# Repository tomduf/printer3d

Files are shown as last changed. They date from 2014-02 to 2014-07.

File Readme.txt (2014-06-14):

Imprimante 3D
Lycée Condorcet - Montreuil

1. Origine du projet
Suite à la découverte de l'expérience "manuelle" d'imprimante 3D proposée par l'université de l'Illinois,
l'idée est venue de proposer la réalisation d'un imprimante 3D dans le cadre des projets pluridisciplinaires de
Terminale SI (Sciences de l'Ingénieur).
Une équipe de quatre élèves a choisi ce projet en septembre 2012 :
- Ludovic Araujo
- Thomas Bande
- Max Dumesny
- Clément Soriot

2. Première version
À l'issue du projet  (juin 2013), un prototype fonctionnel mais non finalisé a permis l'impression d'une petite pièce
très détaillée.
La résine a été synthétisée par un professeur du laboratoire de physique-chimie (Nicolas Dubuisson) selon les
recommandations du site de l'Université de l'Illinois.
L'affichage s'effectuait par vidéoprojecteur DPL et un PC via un programme Processing.
La commande du moteur était réalisée par une carte contrôleur Arduino Uno.
Le PC et l'Arduino Uno communiquaient par port série.

3. Version acutelle en cours de développement (2014)
Le projet a été repris avec un objectif de portabilité totale :
- plus de PC externe
- une alimentation unique
- un accès wifi / Ethernet
- un clavier / souris intégré
- transportabilité manuelle

4. La solution retenue est la suivante :
- Raspberry Pi pour le logiciel d'affichage DLP et gestion du serveur d'images
- Serveur node.js
- Affichage par navigateur web (chromium ou autre) avec jquery
- Arduino Uno pour la commande moteur et l'affichage sur petit écran Oled
- Miroir basculant permettant d'afficher les instructions au mur via le vidéoprojecteur
- Clavier / Souris articulé
- Poignée de transport

5. Exécution logiciel
- Ouvrir un terminal
- Lancer l'application sur le Raspberry avec la commande node app.js
- Observer le déroulement du programme dans la console
- Lancer sur le navigateur web http://localhost:3000
- Suivre les instructions

Thomas DUFOUR
Professeur de Sciences de l'Ingénieur
Lycée Condorcet
31 rue Désiré Chevalier
93100 MONTREUIL

thomas.dufour@condorcet93.fr

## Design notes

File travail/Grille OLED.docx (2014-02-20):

Mode drawFastVLine(48, 0, 48, WHITE); | Cycle drawFastHLine(0, 48, 96, WHITE); drawFastHLine(0, 32, 96, WHITE); drawFastHLine(0, 16, 96, WHITE);
Couche | 43 / 57
Hauteur | -0.32 mm
État | > Up ...

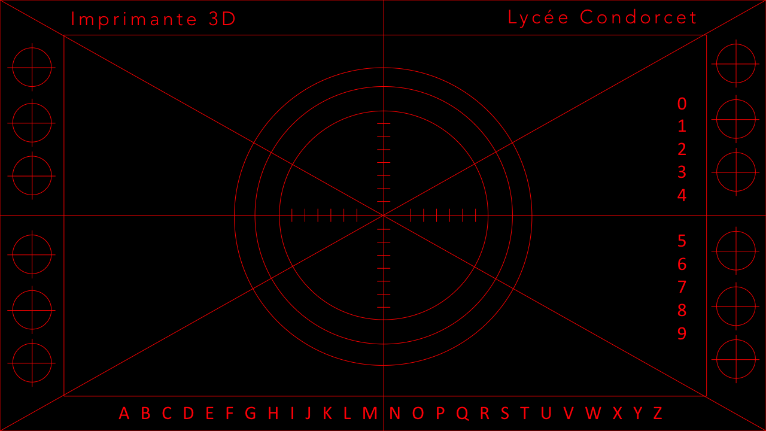
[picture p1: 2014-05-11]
public/images/mire_mise_au_point.png

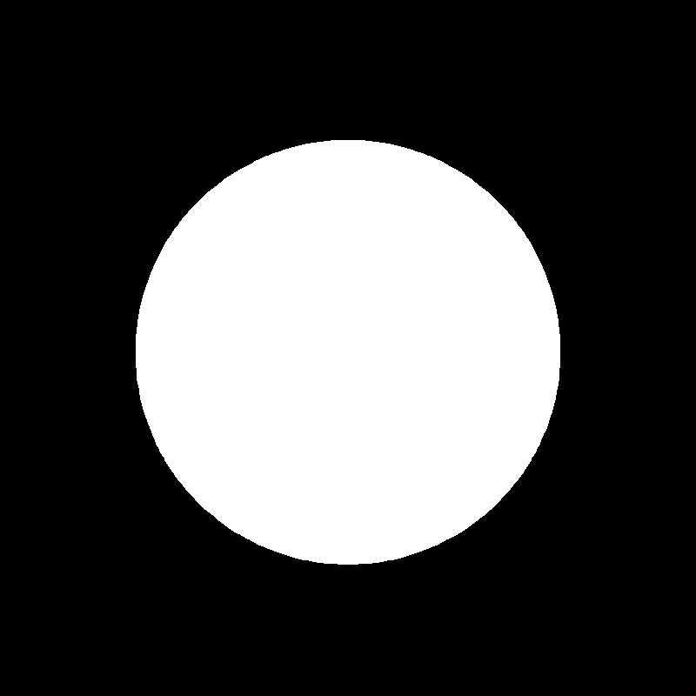
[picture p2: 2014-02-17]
travail/slices-octo-57/layer_0040(z=40.001).png

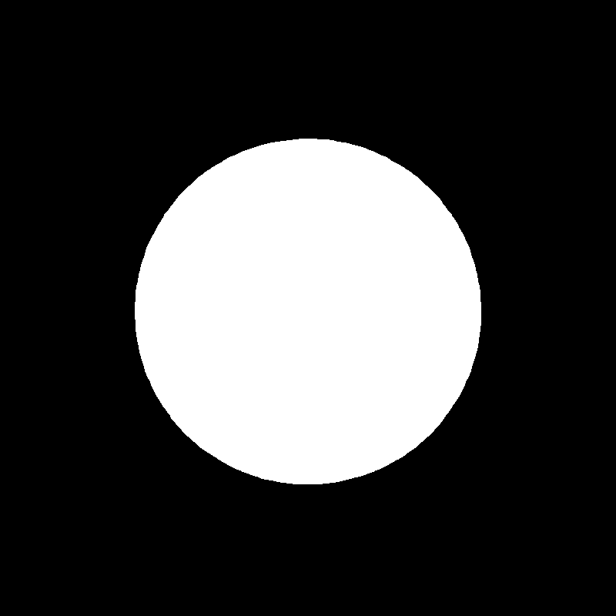
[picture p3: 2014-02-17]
travail/slices-octo-57/layer_0045(z=45.001).png

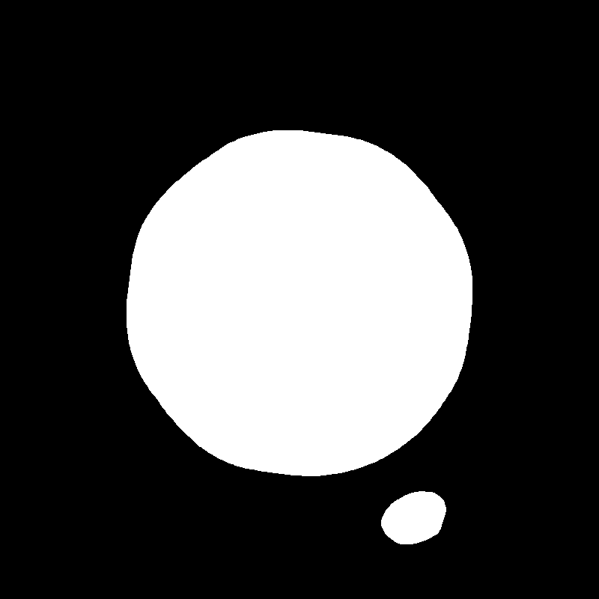
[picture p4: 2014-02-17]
travail/slices-octo-57/layer_0017(z=17.000).png

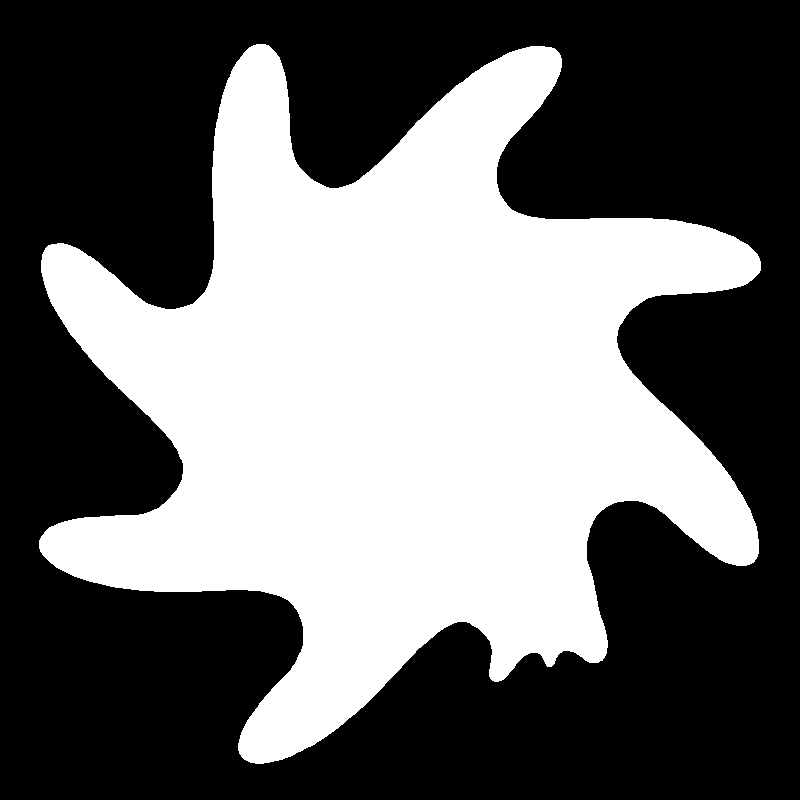
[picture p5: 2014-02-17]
travail/slices-ocot-10/layer_0003(z=3.001).png

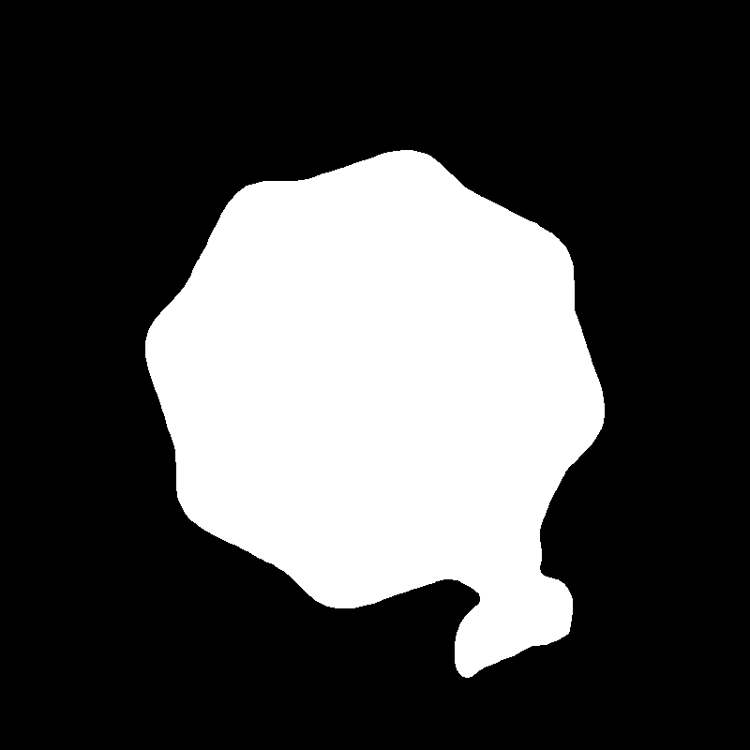
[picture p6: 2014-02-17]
travail/slices-ocot-10/layer_0008(z=8.000).png

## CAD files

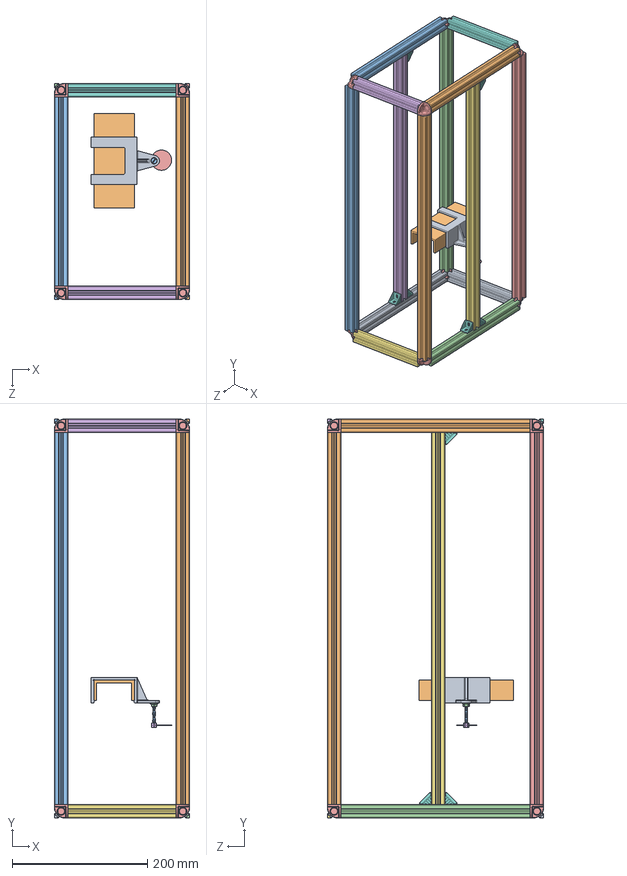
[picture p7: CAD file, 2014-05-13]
travail/solidworks/printer3d.SLDASM
200.0 x 590.0 x 320.0 mm
Profilé - 20x20x280mm - 2
Profilé - 20x20x280mm - 1
Profilé - 20x20x280mm - 3
Profilé - 20x20x280mm - 4
Cornière d'angle - rainure 6mm x 8
Profilé - 20x20x160mm - 1
Profilé - 20x20x160mm - 2
Profilé - 20x20x160mm - 3
Profilé - 20x20x160mm - 4
Profilé - 20x20x550mm - 1
Profilé - 20x20x550mm - 2
Profilé - 20x20x550mm - 3
Profilé - 20x20x550mm - 4
Profilé - 20x20x550mm - 5
Profilé - 20x20x550mm - 6
Equerre x 6
Support clipsable
Copie de Cornière alu^Coulisseau - Plongeur_printer3d
slotted countersunk flat head screw_iso
hex flange nut gradea_iso
Copie de Disque^Coulisseau - Plongeur_printer3d
hex nut style 1 gradeab_iso x 2

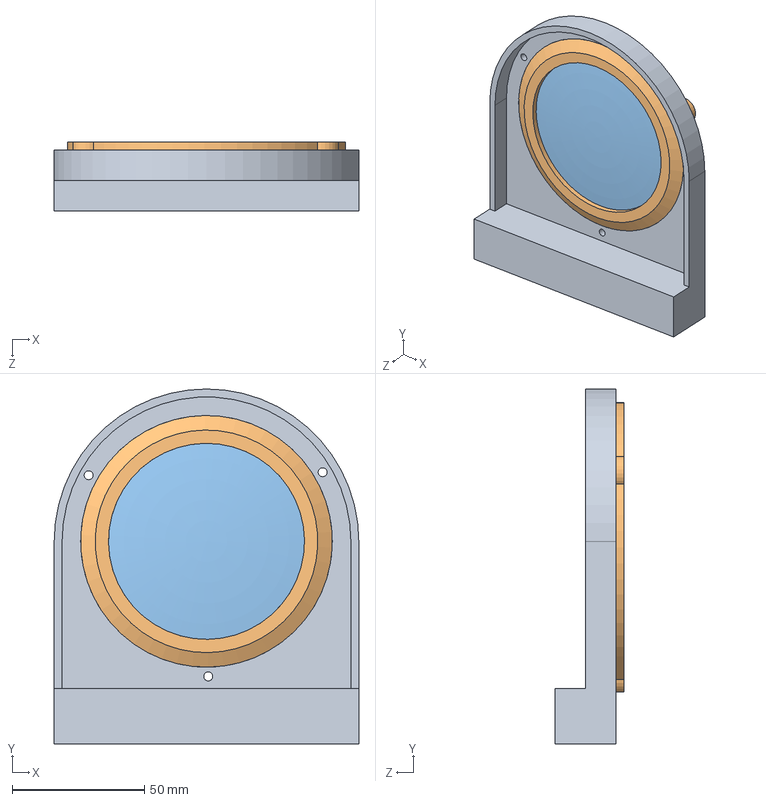
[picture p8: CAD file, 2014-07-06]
travail/Support lentille articulé.SLDASM
115.0 x 134.0 x 26.0 mm
Support lentille
Pièce adaptatrice lentille
Lentille

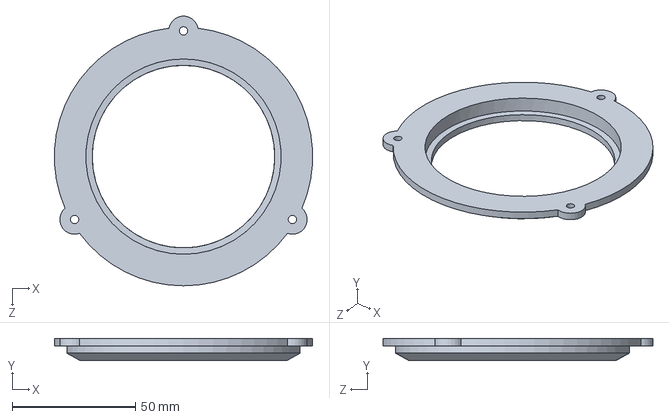
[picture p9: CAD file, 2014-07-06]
travail/Pièce adaptatrice lentille.SLDPRT
104.6 x 9.00 x 109.4 mm

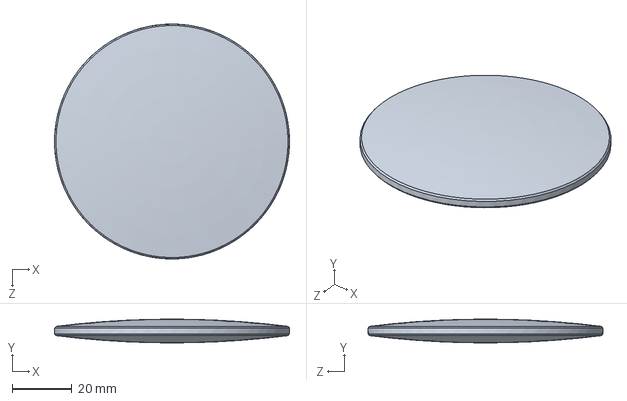
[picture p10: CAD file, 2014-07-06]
travail/Lentille.SLDPRT
79.0 x 8.00 x 79.0 mm

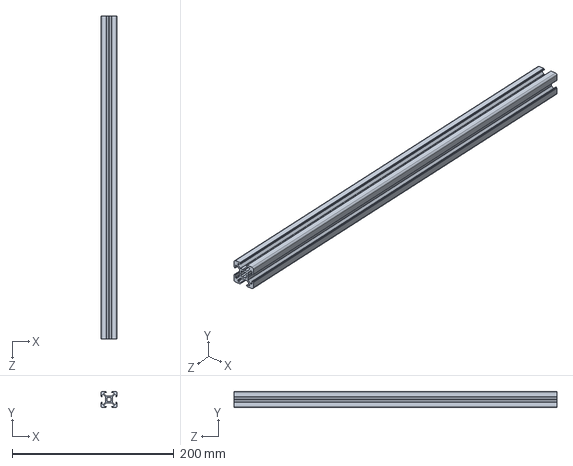
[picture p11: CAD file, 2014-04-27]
travail/solidworks/Profilé - 20x20x550mm - 5.SLDPRT
20.0 x 20.0 x 400.0 mm

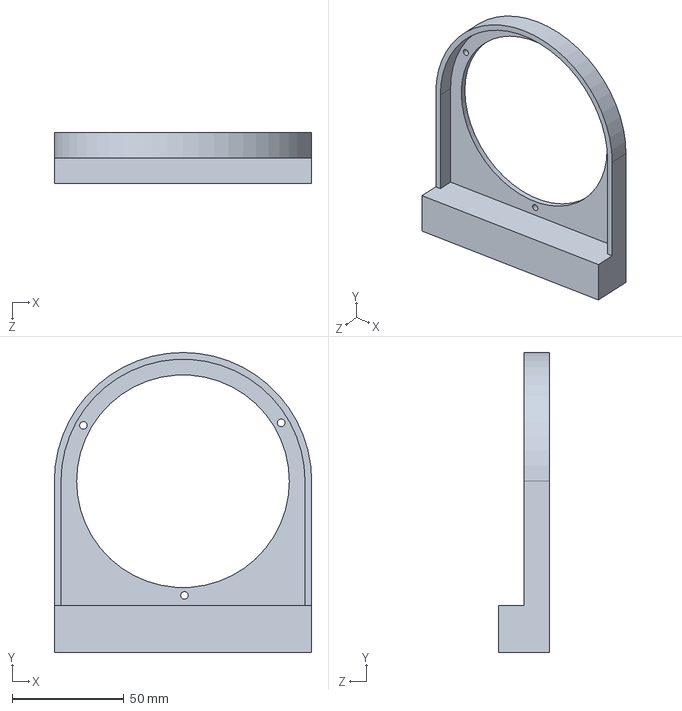
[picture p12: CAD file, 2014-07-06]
travail/Support lentille.SLDPRT
115.0 x 134.0 x 23.0 mm

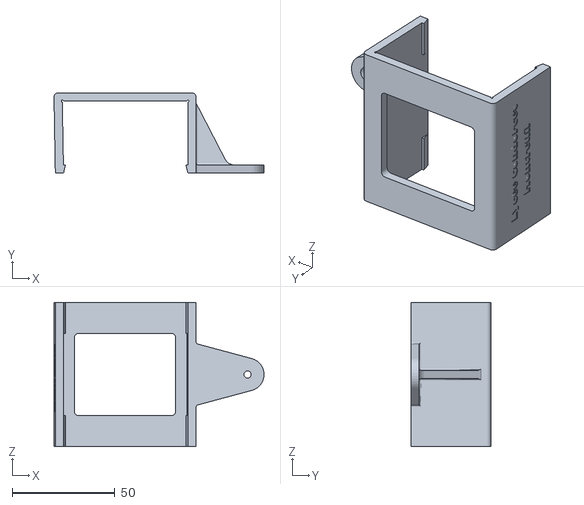
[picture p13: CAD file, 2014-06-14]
travail/Support clipsable.STL
102.0 x 39.0 x 70.0

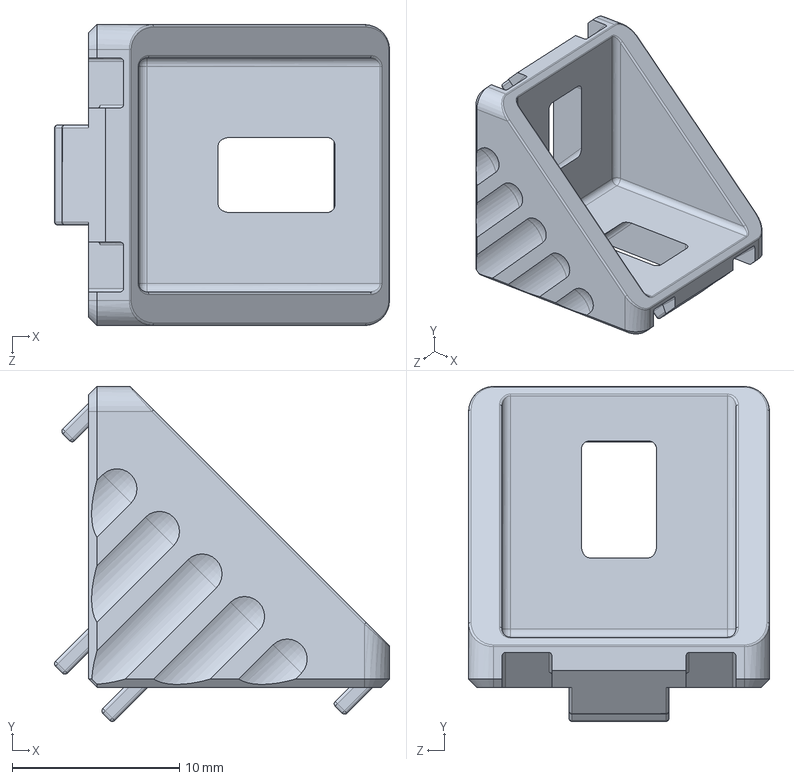
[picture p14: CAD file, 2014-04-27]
travail/solidworks/Equerre.SLDPRT
20.0 x 20.0 x 18.0 mm

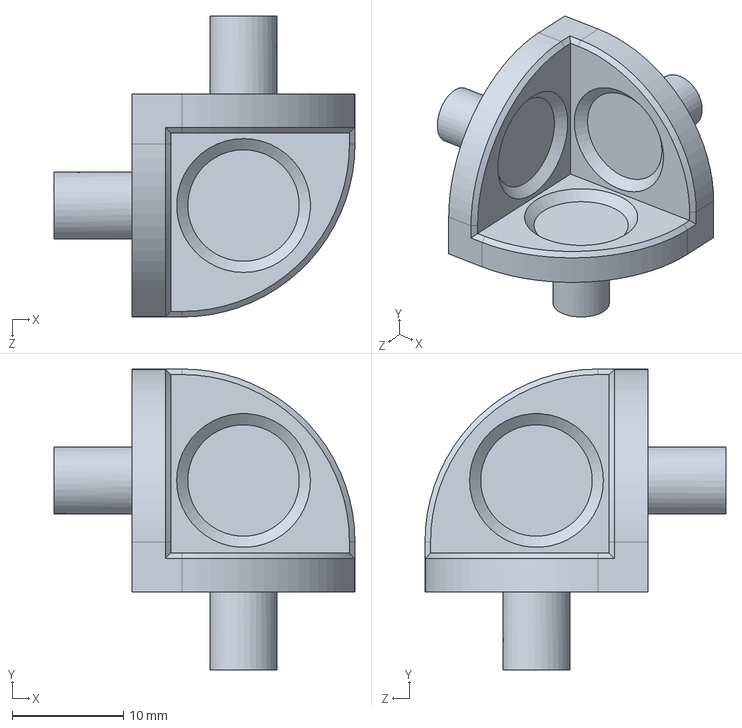
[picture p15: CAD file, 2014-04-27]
travail/solidworks/Cornière d'angle - rainure 6mm.SLDPRT
27.0 x 27.0 x 27.0 mm

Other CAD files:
travail/solidworks/Profilé - 20x20x160mm - 4.SLDPRT
travail/solidworks/Profilé - 20x20x160mm - 1.SLDPRT
travail/solidworks/Profilé - 20x20x280mm - 1.SLDPRT
travail/solidworks/Profilé - 20x20x280mm - 4.SLDPRT
travail/solidworks/Profilé - 20x20x280mm - 2.SLDPRT
travail/Pièce adaptatrice lentille.STL
travail/Support lentille articulé.SLDDRW
travail/solidworks/Profilé - 20x20x160mm - 2.SLDPRT
travail/solidworks/Profilé - 20x20x160mm - 3.SLDPRT
travail/solidworks/Profilé - 20x20x280mm - 3.SLDPRT
travail/solidworks/Rexroth-3 842 992 888_400MM.SLDPRT
travail/solidworks/Rexroth-ecrou M4.SLDPRT

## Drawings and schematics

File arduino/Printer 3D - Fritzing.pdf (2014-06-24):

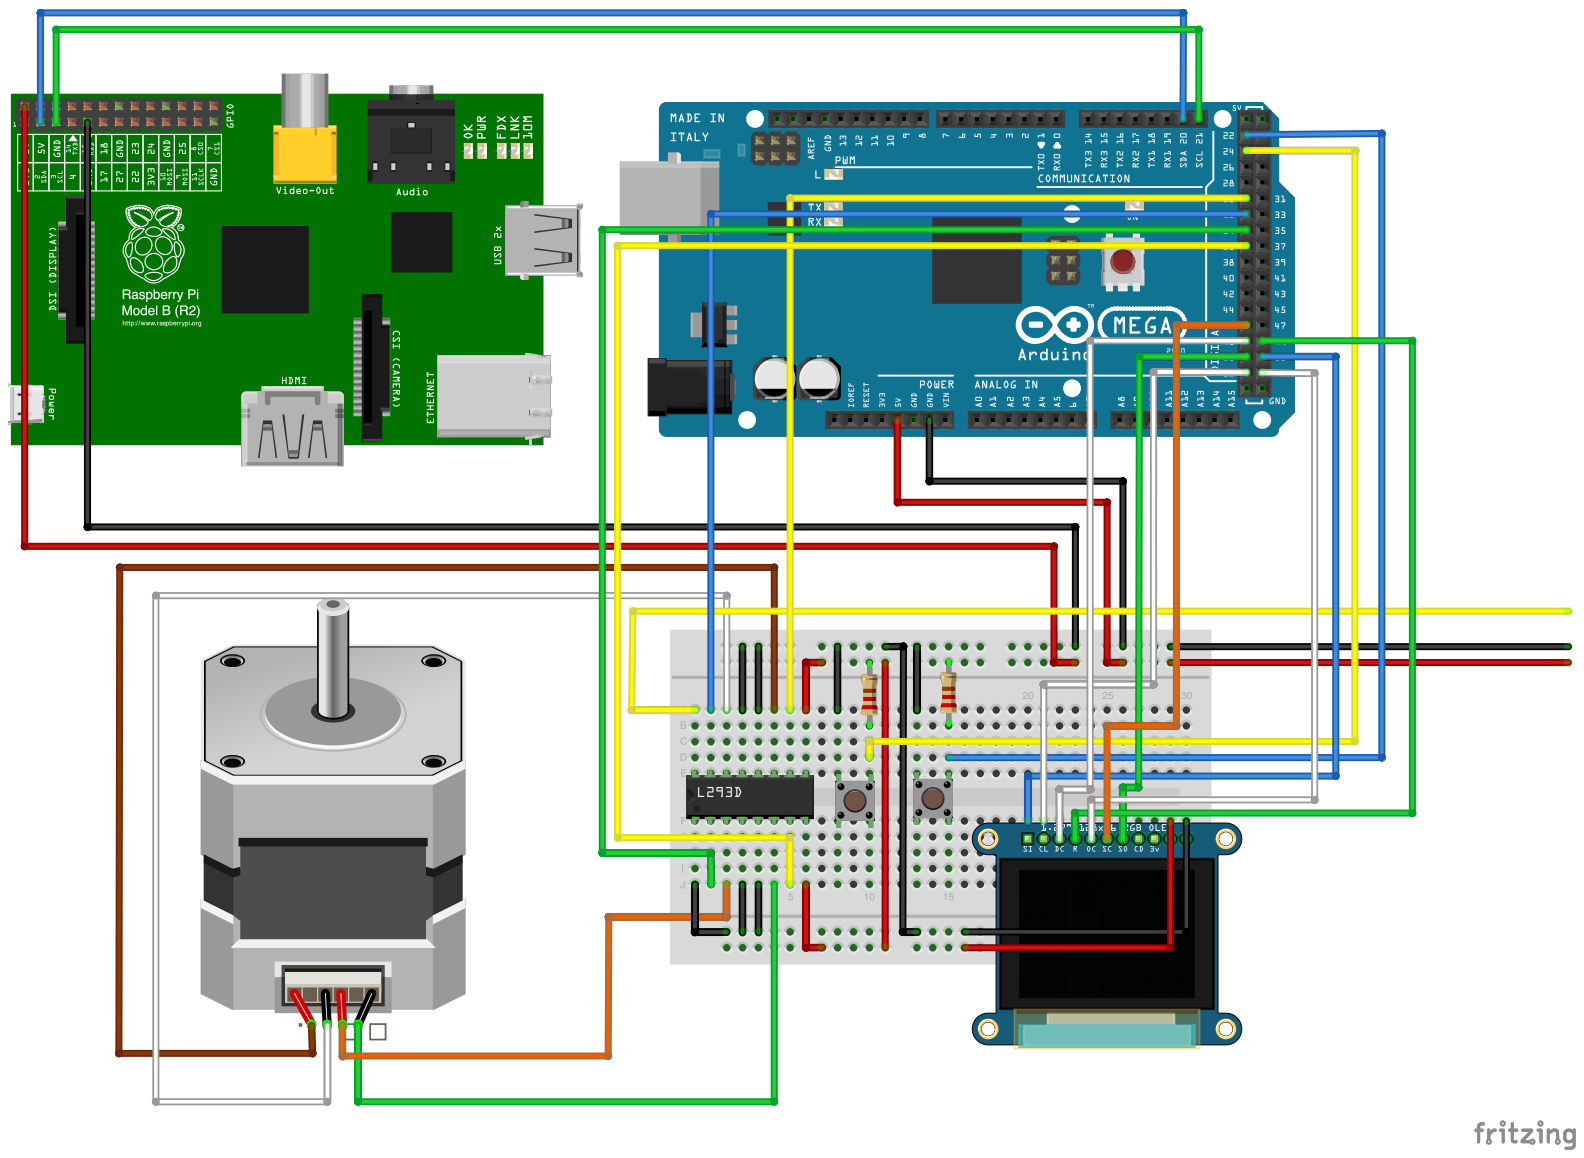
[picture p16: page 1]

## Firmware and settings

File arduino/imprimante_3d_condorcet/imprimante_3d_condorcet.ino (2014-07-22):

/*
 Programme utilisé en combinaison avec le Raspberry Pi
 */

#include <Wire.h>              // Gestion de l'i2c
#include <Stepper.h>           // Gestion du moteur PAP
#include <SD.h>                // Gestion de la carte SD de l'écran
#include <SPI.h>               // Gestion du SPI
#include <Adafruit_GFX.h>      // Bibli Adafruit d'affichage sur l'écran Oled
#include <Adafruit_SSD1331.h>  // Gestion de l'écran Oled

// liaison i2c sur le port 5 avec l'Arduino
#define ARDUINO_ADDRESS 0x05

// déclaration des broches pour l'écran (avec SPI)
#define sclk                52 // 13
#define mosi                51 // 11
#define cs                  53 // 10
#define rst                 49 // 9
#define dc                  48 // 8

// déclaration des boutons de commande manuelle du moteur
#define boutonStop          26
#define boutonBas           24
#define boutonHaut          22

// déclaration des modes de fonctionnement de l'imprimante
#define modeStop            0
#define modeHaut            1
#define modeBas             2
#define modePrint           3
#define modeEtatDiapo       4
#define modePriseRef        5
#define modePlateau         7
#define modeCycle           9
#define modeConfig          10
#define modePrincipal       11

#define ecran1              1
#define ecran2              2
#define ecran3              3
#define ecran4              4
#define ecran5              5
#define ecran6              6

// définition des valeurs de messages entre le RPi et l'Arduino
#define messageStop         0
#define messagefinRemontee  6
#define messagefinCycle     8

// pour Arduino Uno/Duemilanove, etc
// MOSI sur la broche 11 uno, 51 mega
// MISO sur la broche 12, 50 mega
// SCK sur la broche 13 (standard), 52 mega
// ensuite la broche 4 va vers CS (or whatever you have set up) sur mega 46
#define SD_CS 46    // Set the chip select line to whatever you use (4 doesnt conflict with the library)

// définition des couleurs
#define	BLACK           0x0000
#define	BLUE            0x001F
#define	RED             0xF800
#define	GREEN           0x07E0
#define CYAN            0x07FF
#define MAGENTA         0xF81F
#define YELLOW          0xFFE0
#define WHITE           0xFFFF

#define BUFFPIXEL       20

// déclaration de l'écran tft pour afficher les images de la carte SD
Adafruit_SSD1331 tft = Adafruit_SSD1331(cs, dc, rst);

// Déclaration des variables
int vitesse =           100;
int mode =              0;
int pas =               0;
int etatBas, etatStop, etatHaut;

String texteInfo;
boolean changerTexte(false), modifConfig(false);
boolean appuiHaut, appuiBas, appuiStop;

// nombre de pas du moteur 42BYG304
const float stepsPerRevolution(200);

// caractéristiques mécaniques
const int pasVis(1); // mm
float epaisseurCouche(10); // en 1/100 mm
float hauteur(0);

short int numCouche(1);
short int nbCouches(10);
short int nbExpCouche(3);
short int profPlongee(5);  // en mm
short int etatDiapo(0);
short int intervalleEntreExp(1); // en secondes
short int tempsArretAvantRemontee(100); // en millisecondes
short int tempsPauseAvantExpo(100);  // en millisecondes

// nombre de pas de descente par cycle (en fonction de la profondeur de plongée)
short int pasCycleDown = (int)(profPlongee * stepsPerRevolution / pasVis);
// si une révolution fait 200 pas, et que la vis a un pas de 1mm, alors 20 pas font 1/10ème mm
short int pasParCouche = (int)(0.01 * epaisseurCouche * stepsPerRevolution / pasVis);
// nombre de pas pour la remontée d'un cycle
short int pasCycleUp = pasCycleDown - pasParCouche;
// on remonte de la valeur initiale plus 1 cm = 10mm
short int pasRemontee = nbCouches * pasParCouche + (int)(20 * stepsPerRevolution / pasVis);
// Etat de position du moteur en pas (à intialiser à la prise de référence sur le bouton stop)
short int nbPasMoteur = 999;

// Déclaration des ports pour le moteur
// Initialisation de la bibliothèque (dans le tuto initial : broches 8 à 11, sur le mega 30 à 36 par pas de 2, sur uno 2,3, 5, 6) :

Stepper myStepper(stepsPerRevolution, 30, 32, 34, 36);

// fichier image
File bmpFile;

// informations à extraire du fichier image
int bmpWidth, bmpHeight;
uint8_t bmpDepth, bmpImageoffset;

void setup() {
  Serial.begin(9600);
  // initialisation de l'i2c comme esclave
  Wire.begin(ARDUINO_ADDRESS);
  // Déclencheur à la réception de données
  Wire.onReceive(receptionDonnees);
  // Déclencheur lors d'une requete du RPi
  Wire.onRequest(envoiMode);
  // Initialisation de la vitesse du moteur
  myStepper.setSpeed(vitesse);
  // intialisation des boutons
  pinMode(boutonBas, INPUT);
  pinMode(boutonStop, INPUT);
  pinMode(boutonHaut, INPUT);
  // Activation de la connexion avec la SD card
  pinMode(cs, OUTPUT);
  digitalWrite(cs, HIGH);
  // intialisation de l'écran OLED
  tft.begin();
  tft.fillScreen(WHITE);

  // Affichage de l'écran d'accueil
  if (SD.begin(SD_CS))
    bmpDraw("logo.bmp", 0, 0);
  // Affichage du mode principal
  mode = modePrincipal;
}

void loop() {
  if (modifConfig)
    mode = modeConfig; // artifice pour passer de l'octet 0x0A à l'integer 10...

  // Appuis sur les boutons. Par sécurité, la pression doit etre maintenue
  etatStop = digitalRead(boutonStop); // bouton de prise de référence supérieure en début de programme
  if (etatStop == LOW) { // bouton de fin de course haut et prise de référence
    mode = modeStop;
    nbPasMoteur = 0; //  RAZ de la référence moteur
  }
  etatBas = digitalRead(boutonBas);
  if (etatBas == LOW) { // si bouton bas appuyé
    mode = modeBas;   // on se place en mode "descente"
    appuiBas = true;  // et en mode "bouton appuyé"
  }
  else if (appuiBas) { // si on n'appuie plus alors qu'on était en mode "bouton appuyé"
    mode = modeStop;   // alors on se place en mode "stop"
    appuiBas = false;  // et on remet le mode à "bouton relevé"
  }

  etatHaut = digitalRead(boutonHaut);
  if (etatHaut == LOW) {
    if (etatStop != LOW){ // Par sécurité on ne peut pas aller plus loin que la fin de course
      mode = modeHaut;
      appuiHaut = true;
    }
  }
  else if (appuiHaut) {
    mode = modeStop;
    appuiHaut = false;
  }

  // Appel au balayage de tous les modes
  balayageModes();
}

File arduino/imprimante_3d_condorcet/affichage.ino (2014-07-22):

// affichage de la grille et des textes statiques
void affichageGrille(){
  // Fond blanc
  tft.fillScreen(WHITE);
  // Grille avec des lignes rapides
  // Trois lignes horizontales
  tft.drawFastHLine(0, 16, 96, BLACK);
  tft.drawFastHLine(0, 32, 96, BLACK);
  tft.drawFastHLine(0, 48, 96, BLACK);
  // Une ligne verticale
  tft.drawFastVLine(48, 0, 64, BLACK);
  
  // Affichage ligne 1 (Mode)
  tft.setTextColor(BLACK);
  tft.setCursor(4,5);
  tft.print("Mode");

  // Affichage ligne 2 (Hauteur)
  tft.setCursor(4,21);
  tft.print("Hauteur");

  // Affichage ligne 3 (Couche / nb couches)
  tft.setCursor(4,37);
  tft.print("Couche");
  tft.setCursor(72,37);
  tft.print("/");

  // Affichage ligne 4 (Etat)
  tft.setTextColor(BLACK);
  tft.setCursor(4,53);
  tft.print("Etat");
}

// affichage et rafraichissement des textes variables sur quatre lignes
void affichageTexte(String text1, String text2, int text3, String text4){
  // Affichage du mode
  tft.setTextColor(BLUE);
  tft.fillRect(52, 5, 30, 10, WHITE);
  tft.setCursor(52,5);
  tft.print(text1);
  
  // Affichage de la hauteur
  tft.setTextColor(BLACK);
  tft.fillRect(52, 21, 30, 10, WHITE);
  tft.setCursor(52,21);
  tft.print(text2);

  // Affichage de la couche active / nb couches
  tft.setTextColor(RED);
  tft.fillRect(52, 37, 25, 10, WHITE);
  tft.setCursor(52,37);
  tft.print(text3);
  
  /*tft.setTextColor(BLACK);
  tft.setCursor(78,37);
  tft.print(nbCouches);*/
  
  // Affichage de l'état
  tft.setTextColor(GREEN);
  if (etatDiapo == 0 )
    tft.fillRect(52, 53, 30, 10, WHITE);
  tft.setCursor(52,53);
  tft.print(text4);
  
  if (etatDiapo > 0){
    tft.fillRect(52, 53, 30, 10, WHITE);
    tft.fillCircle(58, 56, 5, GREEN);
  }
  if (etatDiapo > 1)
    tft.fillCircle(72, 56, 5, GREEN);
  if (etatDiapo > 2)
    tft.fillCircle(86, 56, 5, GREEN);
}

// surcharge avec un seul texte (efface tout)
void affichageTexte(String text){
  // Affichage du fond blanc
  tft.fillScreen(WHITE);
  tft.setTextColor(BLACK);
  tft.setCursor(5,20);
  tft.print(text);
}
// surcharge avec un seul texte (entier)
void affichageTexte(int text){
  // Affichage du fond blanc
  tft.fillScreen(WHITE);
  tft.setTextColor(BLACK);
  tft.setCursor(5,20);
  tft.print(text);
}

void affichage(int mode, int ecran){
  switch (mode){
    case modePriseRef :
      switch (ecran) {
        case ecran1 :
          tft.fillScreen(WHITE);
          tft.fillRect(0, 0, 96, 16, BLUE);
          tft.setTextColor(WHITE);
          tft.setCursor(4,5);
          tft.print("Prise de ref");       
          tft.setTextColor(RED);
          tft.setCursor(4,21);
          tft.print("Montee...");       
        break;
        case ecran2 :
          tft.fillRect(0, 21, 95, 10, WHITE);
          tft.setTextColor(GREEN);
          tft.setCursor(4,21);
          tft.print("Fin de course");
          delay(1000);     
          tft.setTextColor(RED);
          tft.setCursor(4,37);
          tft.print("Descente 750");       
        break;
        case ecran3 :
          tft.setTextColor(GREEN);
          tft.setCursor(4,21);
          tft.fillRect(0, 21, 95, 10, WHITE);
          tft.print("Operation OK");       
          tft.fillRect(0, 37, 95, 10, WHITE);
          tft.fillRect(0, 53, 52, 10, WHITE);
          tft.setTextColor(BLUE);
          tft.setCursor(4,53);
          tft.print("Nb pas ->");       
          tft.setTextColor(RED);
          tft.setCursor(64,53);
          tft.print(nbPasMoteur);       
        break;
      }
    break;
    case modePrincipal :
      switch (ecran) {
        case ecran1 :
          tft.fillScreen(WHITE);
          tft.fillRect(0, 0, 96, 16, BLUE);
          tft.setTextColor(WHITE);
          tft.setCursor(4,5);
          tft.print("Imprimante 3D");       
          tft.setTextColor(GREEN);
          tft.setCursor(4,21);
          tft.print("En attente");       
          tft.setCursor(4,37);
          tft.print("Raspberry Pi");       
          tft.setCursor(4,53);
          tft.setTextColor(BLUE);
          tft.print("Stop");       
          tft.setTextColor(RED);
          tft.setCursor(70,53);
          tft.print(nbPasMoteur);       
        break;
      }
    break;
    case modeConfig :
      switch (ecran) {
        case ecran1 :
          tft.fillScreen(WHITE);
          tft.fillRect(0, 0, 96, 16, BLUE);
          tft.setTextColor(WHITE);
          tft.setCursor(4,5);
          tft.print("Configuration");       
          tft.setTextColor(GREEN);
          tft.setCursor(4,21);
          tft.print("Epaisseur ");       
          tft.setCursor(60,21);
          tft.print(epaisseurCouche);       
        break;
      }
    break;
    case modeStop :
      switch (ecran) {
        case ecran1 :
          tft.fillRect(0, 53, 96, 10, WHITE);
          tft.setTextColor(BLUE);
          tft.setCursor(4,53);
          tft.print("Stop");       
          tft.setTextColor(RED);
          tft.setCursor(64,53);
          tft.print(nbPasMoteur);
          envoiPas();     
        break;
      }
    break;
    case modeHaut :
      switch (ecran) {
        case ecran1 :
          tft.fillRect(0, 53, 52, 10, WHITE);
          tft.setTextColor(BLUE);
          tft.setCursor(4,53);
          tft.print("Haut");       
        break;
      }
    break;
    case modeBas :
      switch (ecran) {
        case ecran1 :
          tft.fillRect(0, 53, 52, 10, WHITE);
          tft.setTextColor(BLUE);
          tft.setCursor(4,53);
          tft.print("Bas");       
        break;
      }
    break;
  }
}

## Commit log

2014-02-15 Première foi que l'i2c écrit sur Arduino !
2014-02-15 Version stable sans i2c avec code Arduino
2014-02-15 Intégration de i2c qui fait tourner le moteur
2014-02-15 de mieux en mieux... affichage de points pour le cycle moteur un peu moins serait mieux
2014-02-15 Bonne version. Affichage des points corrects. Quelques bizarreries : > parfois le cycle moteur ne dure pas autant > attention, l'image a à peine le temps d'être terminée que le moteur s'en va déjà - 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
2014-02-16 Arduino
    Intégration du cycle moteur
2014-02-18 Nettoyage du fichier Arduino Affichage sur trois lignes
2014-02-18 Erreur sur le numéro de ligne dans l'affichage des diapos
2014-02-20 Nettoyage programme Arduino
2014-02-20 Arduino Grille ok
    Reste les valeurs à intégrer, notamment les cycles
2014-02-20 Réorganisation des diapos - quatre paramètre affichage
    - Juste 10 diapos
    - quatrième ligne pour l’affichage
2014-02-20 Erreurs programmes Arduino
2014-02-20 Bonne version
    - Grille ok
    - Couche ok mais à incrémenter
    - Pas de remontée plateau
2014-02-20 Gestion de fin de cycle
2014-02-20 Intégration du mode cycle en affichage sur l'ARduino
2014-02-20 Erreur d'i2C. Envoi de 3 pour le modePrint
2014-02-20 Moins de points durant les cycles
2014-02-20 Très bonne version
    Reste à faire :
    - Calcul et affichage de la hauteur
    - Rafraîchissement moins radical. Juste les valeurs à changer
    - Accents
2014-02-21 Ajout d'une fonction etatDiapo
    appelée à l’événement fadeIn
2014-02-21 Bonne version avant ski
    Tout marche bien :
    - plus de problèmes de cycle moteur
    - ronds verts ok
    A faire :
    - calcul et affichage de la hauteur
    - Réinitialisation au début (appel i2c)
    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
2014-03-03 Avant fusion des branches
2014-03-07 Mise en place de la caméra
2014-03-08 Redimmensionnement camera
2014-03-08 Rotation camera
2014-03-08 Intégration de l'image dans le haut de la page taille : 400x300
2014-03-21 Mises à jour de modules
2014-03-28 Modules et arduino
2014-04-04 Simplification du code Arduino
2014-04-11 Améliorations Arduino
    Encore des problèmes de rafraîchissement
2014-04-27 Sauvegarde avant gros chamboulement
    Réparation de l’erreur Arduino
    Console Serial pour diagnostiquer le pb
    [All_Straight.SLDPRT, BlackConnectorSmall.SLDPRT, BlueConnectorCross_Tube.SLDPRT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]
2014-05-11 Résolution 1280x720px
    [All_Straight.SLDPRT, BlackConnectorSmall.SLDPRT, BlueConnectorCross_Tube.SLDPRT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]
2014-05-11 Recentrage des vignettes
2014-05-11 Remontée des vignettes
2014-05-11 Restauration Solidworks
    [Cornière d'angle - rainure 6mm.SLDPRT, Equerre.SLDPRT, Profilé - 20x20x160mm - 1.SLDPRT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]
2014-05-13 mise à niveau
    [Support clipsable.SLDPRT, Support clipsable.STL, printer3d.SLDASM]
2014-05-13 Ajout de champs pour Arduino
2014-05-14 Envoi config Arduino, premiers essais
2014-05-14 Conversion hexa des valeurs de config
2014-05-14 Test des vraies valeurs transmises à l'aRduino converties en hexa
2014-05-14 Test des vraies valeurs transmises à l'aRduino converties en hexa; suite avec req.params.
2014-05-14 Envoi des six valeurs en paramètre
2014-05-14 Test réel des valeurs transmises
2014-05-21 Config ok mais difficile à modifier
    Dès qu’on ajoute un Serial.println, il y a un problème
2014-05-23 Config ok et valeurs interprétées par l'Arduino
2014-05-23 Config ok et valeurs interprétées par l'Arduino et inde.ejs
2014-06-14 Images lycée
    [Support clipsable.SLDPRT, Support clipsable.STL]
2014-06-17 Config Arduino Masquées
2014-06-17 Config Arduino Masquées - avec liens...
2014-06-24 Mega en place
    Tout fonctionne mieux avec l’Arduino Mega. Plus de mémoire, et plus
    fiable que l’Arduino Uno Rev 2
    [Schema.fzz]
2014-07-06 Mega - Bague - Prise de réf
    Plein de nouveautés :
    - Utilisation d’un Arduino Mega permettant de connecter plus de boutons
    et capteurs. Programme plus lourd et plus rapide
    - Schéma Fritzing complet
    - Bouton fin de course pour la prise de référence
    [Lentille.SLDPRT, Pièce adaptatrice lentille.SLDPRT, Pièce adaptatrice lentille.STL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]
2014-07-08 Améliorations affichage
    Progression dans les écrans d’affichage. Config par exemple
2014-07-21 Ajout de la durée d'exposition
2014-07-22 Démarrage de la prise de référence par le RPi
    On ne lance plus cette étape à l’allumage, mais au lancement du
    programme app.js
2014-07-22 Lecture Arduino - motif fonction
